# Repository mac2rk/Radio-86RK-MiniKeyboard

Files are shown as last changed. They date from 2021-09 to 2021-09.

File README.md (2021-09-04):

# Mini Keyboard for Radio-86RK

A mini keyboard for Radio-86RK, a 1986 DIY 8-bit home computer.
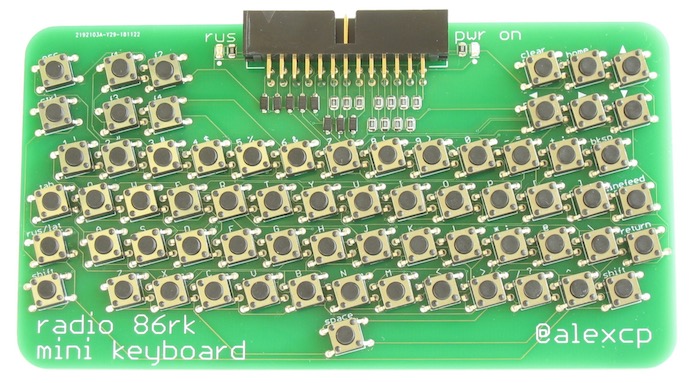
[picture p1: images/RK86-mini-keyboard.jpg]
Radio-86RK Mini Keyboard


## Introduction

When I designed my [Radio-86RK-SRAM](https://github.com/mac2rk/Radio-86RK-SRAM) remake of the 1986 DIY 8-bit home computer, I built in a PS/2 keyboard adapter to stay away from homebrew keyboards and use a commercial full-size keyboard instead. I found, however, that in many cases the full size keyboard took too much space, so I designed a mini matrix keyboard built from tact momentary switches. The design was inspired by the [Hackaday Belgrade 2018 conference badge](https://hackaday.com/2018/05/15/retro-computer-badge-for-hackaday-belgrade-has-everything-you-wished-for-back-in-the-day/).

Due to the large number of SMT tact buttons, it is easier to solder in an SMT over or with hot air. Normal manual soldering is quite possible, too.

## Schematic and PCB layout
[Schematic](Eagle/rk86-kbd-schematic.pdf)

[PCB layout](Eagle/rk86-kbd-silk.pdf)

## Bill of Materials

Device                | Package   | Quantity
--------------------- | --------- | -------
Tact momentary switch | 6x6mm SMT | 67
Resistor 2kOhm        | 0805      | 11
Resistor 330Ohm       | 0805      | 2
1N4148W diode         | SOD-123   | 8
LED                   | 0805      | 2
2x13 box header       | Right Angle | 1

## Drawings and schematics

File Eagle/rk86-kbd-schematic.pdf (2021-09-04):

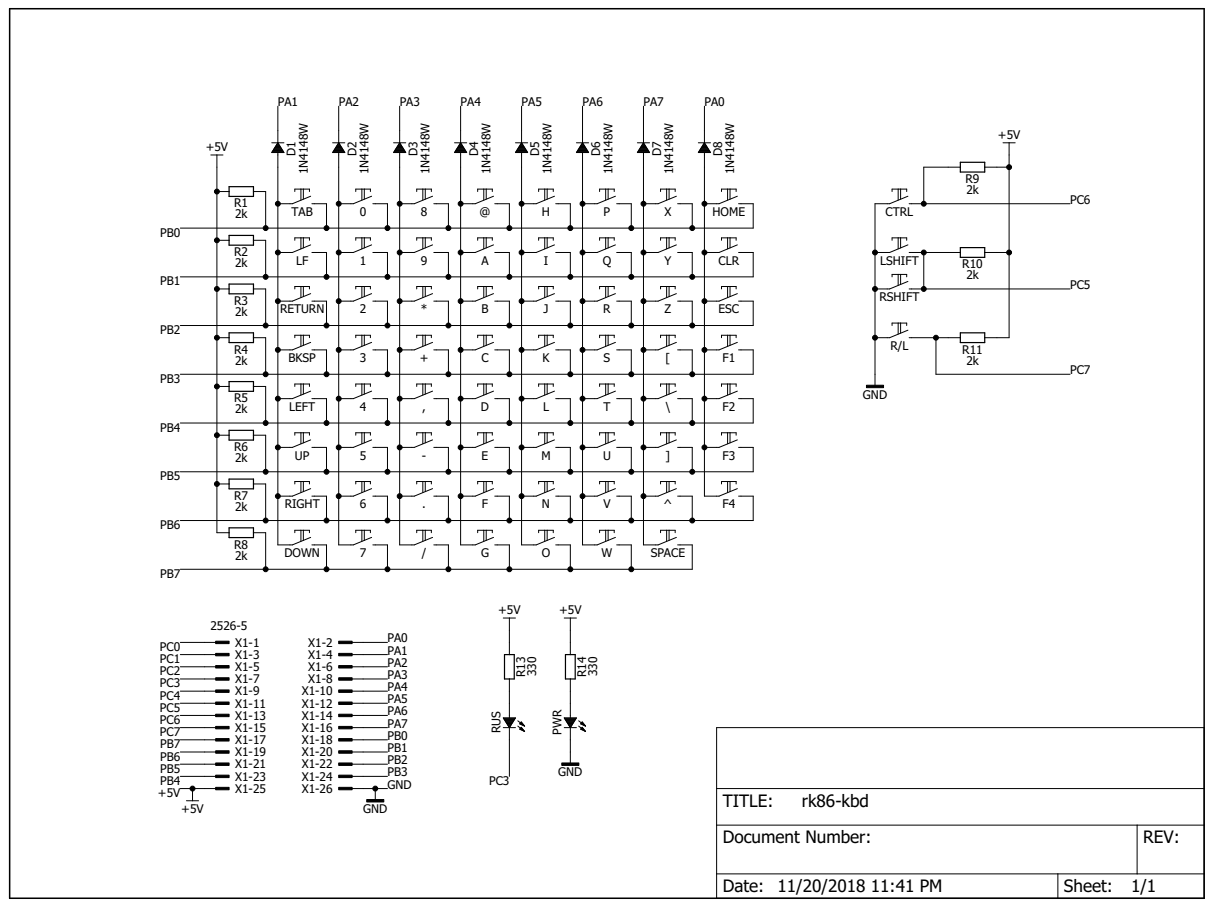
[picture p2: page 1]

Document Number: | REV:

Date: 11/20/2018 11:41 PM | Sheet: 1/1

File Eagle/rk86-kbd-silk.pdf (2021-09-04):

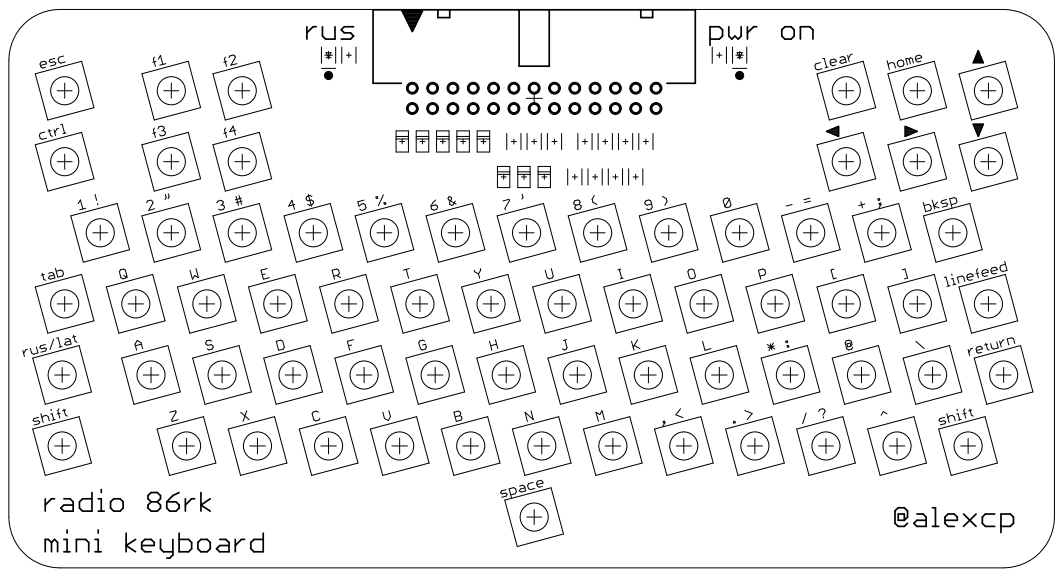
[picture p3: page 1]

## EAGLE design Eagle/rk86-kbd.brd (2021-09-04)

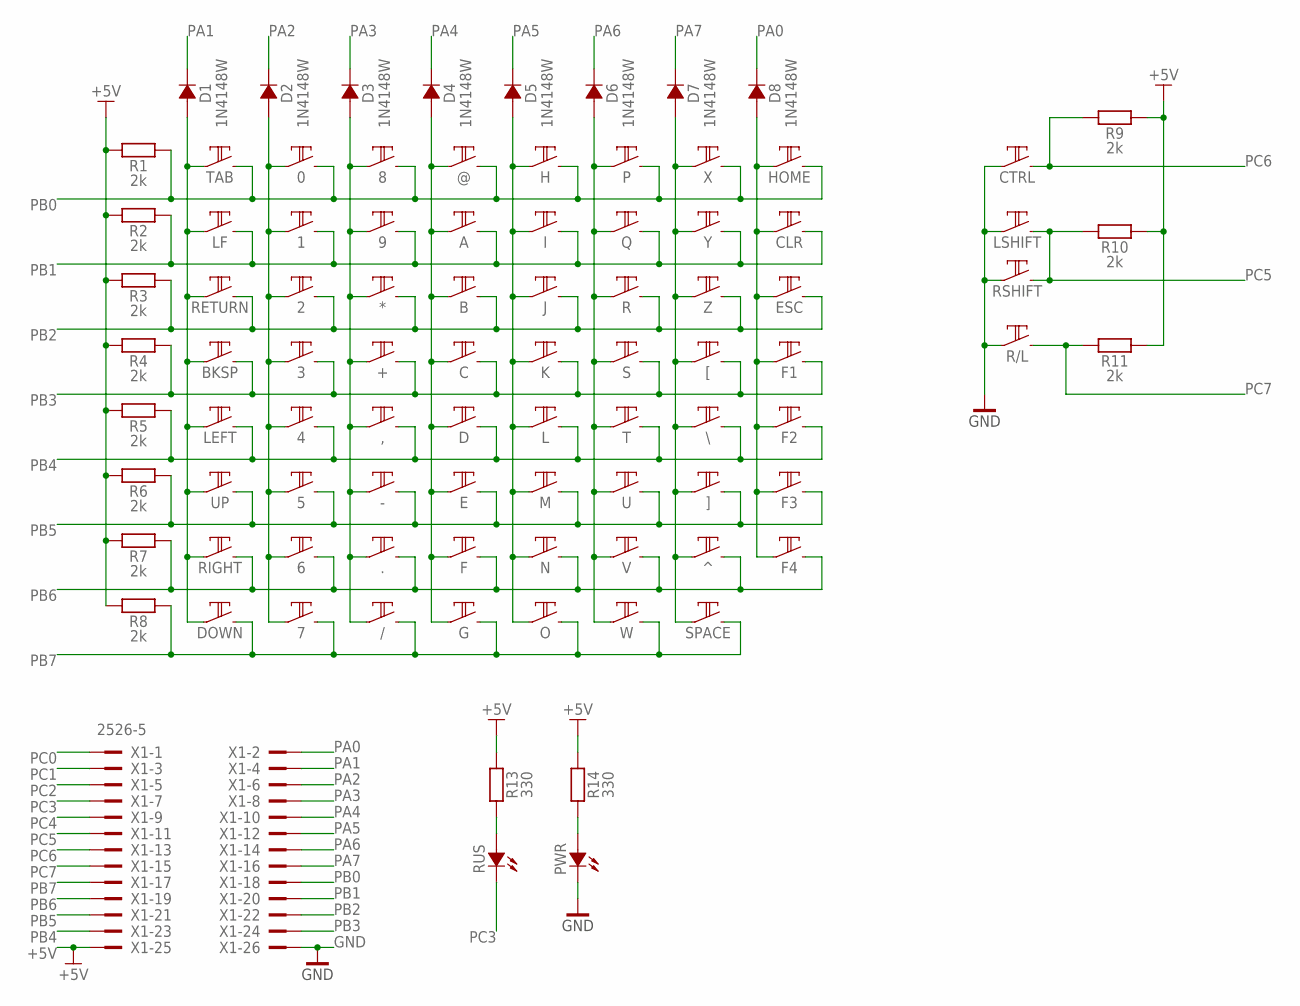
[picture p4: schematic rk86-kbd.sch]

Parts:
0, 1, 2, 3, 4, 5, 6, 7, 8, 9, .: TACT6S-15; TACT_6X6_SMT_15
*: TACT6S-15; TACT_6X6_SMT_15
+: TACT6S-15; TACT_6X6_SMT_15
,: TACT6S-15; TACT_6X6_SMT_15
-: TACT6S-15; TACT_6X6_SMT_15
/: TACT6S-15; TACT_6X6_SMT_15
@: TACT6S-15; TACT_6X6_SMT_15
A: TACT6S-15; TACT_6X6_SMT_15
B: TACT6S-15; TACT_6X6_SMT_15
BKSP: TACT6S-15; TACT_6X6_SMT_15
C: TACT6S-15; TACT_6X6_SMT_15
CLR: TACT6S-15; TACT_6X6_SMT_15
CTRL: TACT6S-15; TACT_6X6_SMT_15
D: TACT6S-15; TACT_6X6_SMT_15
D1, D2, D3, D4, D5, D6, D7, D8: 1N4148W; SOD123
DOWN: TACT6S-15; TACT_6X6_SMT_15
E: TACT6S-15; TACT_6X6_SMT_15
ESC: TACT6S-15; TACT_6X6_SMT_15
F, F1, F2, F3, F4: TACT6S-15; TACT_6X6_SMT_15
G: TACT6S-15; TACT_6X6_SMT_15
H: TACT6S-15; TACT_6X6_SMT_15
HOME: TACT6S-15; TACT_6X6_SMT_15
I: TACT6S-15; TACT_6X6_SMT_15
J: TACT6S-15; TACT_6X6_SMT_15
K: TACT6S-15; TACT_6X6_SMT_15
L: TACT6S-15; TACT_6X6_SMT_15
LEFT: TACT6S-15; TACT_6X6_SMT_15
LF: TACT6S-15; TACT_6X6_SMT_15
LSHIFT: TACT6S-15; TACT_6X6_SMT_15
M: TACT6S-15; TACT_6X6_SMT_15
N: TACT6S-15; TACT_6X6_SMT_15
O: TACT6S-15; TACT_6X6_SMT_15
P: TACT6S-15; TACT_6X6_SMT_15
PWR: LED0805; 0805POL
Q: TACT6S-15; TACT_6X6_SMT_15
R: TACT6S-15; TACT_6X6_SMT_15
R1, R2, R3, R4, R5, R6, R7, R8, R9, R10, R11: 2k; 0805
R13, R14: 330; 0805
R/L: TACT6S-15; TACT_6X6_SMT_15
RETURN: TACT6S-15; TACT_6X6_SMT_15
RIGHT: TACT6S-15; TACT_6X6_SMT_15
RSHIFT: TACT6S-15; TACT_6X6_SMT_15
RUS: LED0805; 0805POL
S: TACT6S-15; TACT_6X6_SMT_15
SPACE: TACT6S-15; TACT_6X6_SMT_15
T: TACT6S-15; TACT_6X6_SMT_15
TAB: TACT6S-15; TACT_6X6_SMT_15
U: TACT6S-15; TACT_6X6_SMT_15
UP: TACT6S-15; TACT_6X6_SMT_15
V: TACT6S-15; TACT_6X6_SMT_15
W: TACT6S-15; TACT_6X6_SMT_15
X: TACT6S-15; TACT_6X6_SMT_15
X1: 2526-5; PAK100/2500-5-26
Y: TACT6S-15; TACT_6X6_SMT_15
Z: TACT6S-15; TACT_6X6_SMT_15
[: TACT6S-15; TACT_6X6_SMT_15
\\: TACT6S-15; TACT_6X6_SMT_15
]: TACT6S-15; TACT_6X6_SMT_15
^: TACT6S-15; TACT_6X6_SMT_15

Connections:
+5V: R1.1, R2.1, R3.1, R4.1, R5.1, R6.1, R7.1, R8.1, R9.2, R10.2, R11.2, R13.2, R14.2, X1.25
GND: CTRL.1 (C), CTRL.2 (C), LSHIFT.1 (C), LSHIFT.2 (C), PWR.K, R/L.1 (C), R/L.2 (C), RSHIFT.1 (C), RSHIFT.2 (C), X1.26
unnamed: R13.1, RUS.A
unnamed: PWR.A, R14.1
PA0: D8.K, X1.2
PA0D: CLR.1 (C), CLR.2 (C), D8.A, ESC.1 (C), ESC.2 (C), F1.1 (C), F1.2 (C), F2.1 (C), F2.2 (C), F3.1 (C), F3.2 (C), F4.1 (C), F4.2 (C), HOME.1 (C), HOME.2 (C)
PA1: D1.K, X1.4
PA1D: BKSP.1 (C), BKSP.2 (C), D1.A, DOWN.1 (C), DOWN.2 (C), LEFT.1 (C), LEFT.2 (C), LF.1 (C), LF.2 (C), RETURN.1 (C), RETURN.2 (C), RIGHT.1 (C), RIGHT.2 (C), TAB.1 (C), TAB.2 (C), UP.1 (C), UP.2 (C)
PA2: D2.K, X1.6
PA2D: 0.1 (C), 0.2 (C), 1.1 (C), 1.2 (C), 2.1 (C), 2.2 (C), 3.1 (C), 3.2 (C), 4.1 (C), 4.2 (C), 5.1 (C), 5.2 (C), 6.1 (C), 6.2 (C), 7.1 (C), 7.2 (C), D2.A
PA3: D3.K, X1.8
PA3D: 8.1 (C), 8.2 (C), 9.1 (C), 9.2 (C), *.1 (C), *.2 (C), +.1 (C), +.2 (C), ,.1 (C), ,.2 (C), -.1 (C), -.2 (C), ..1 (C), ..2 (C), /.1 (C), /.2 (C), D3.A
PA4: D4.K, X1.10
PA4D: @.1 (C), @.2 (C), A.1 (C), A.2 (C), B.1 (C), B.2 (C), C.1 (C), C.2 (C), D.1 (C), D.2 (C), D4.A, E.1 (C), E.2 (C), F.1 (C), F.2 (C), G.1 (C), G.2 (C)
PA5: D5.K, X1.12
PA5D: D5.A, H.1 (C), H.2 (C), I.1 (C), I.2 (C), J.1 (C), J.2 (C), K.1 (C), K.2 (C), L.1 (C), L.2 (C), M.1 (C), M.2 (C), N.1 (C), N.2 (C), O.1 (C), O.2 (C)
PA6: D6.K, X1.14
PA6D: D6.A, P.1 (C), P.2 (C), Q.1 (C), Q.2 (C), R.1 (C), R.2 (C), S.1 (C), S.2 (C), T.1 (C), T.2 (C), U.1 (C), U.2 (C), V.1 (C), V.2 (C), W.1 (C), W.2 (C)
PA7: D7.K, X1.16
PA7D: D7.A, SPACE.1 (C), SPACE.2 (C), X.1 (C), X.2 (C), Y.1 (C), Y.2 (C), Z.1 (C), Z.2 (C), [.1 (C), [.2 (C), \\.1 (C), \\.2 (C), ].1 (C), ].2 (C), ^.1 (C), ^.2 (C)
PB0: 0.3 (NO), 0.4 (NO), 8.3 (NO), 8.4 (NO), @.3 (NO), @.4 (NO), H.3 (NO), H.4 (NO), HOME.3 (NO), HOME.4 (NO), P.3 (NO), P.4 (NO), R1.2, TAB.3 (NO), TAB.4 (NO), X.3 (NO), X.4 (NO), X1.18
PB1: 1.3 (NO), 1.4 (NO), 9.3 (NO), 9.4 (NO), A.3 (NO), A.4 (NO), CLR.3 (NO), CLR.4 (NO), I.3 (NO), I.4 (NO), LF.3 (NO), LF.4 (NO), Q.3 (NO), Q.4 (NO), R2.2, X1.20, Y.3 (NO), Y.4 (NO)
PB2: 2.3 (NO), 2.4 (NO), *.3 (NO), *.4 (NO), B.3 (NO), B.4 (NO), ESC.3 (NO), ESC.4 (NO), J.3 (NO), J.4 (NO), R.3 (NO), R.4 (NO), R3.2, RETURN.3 (NO), RETURN.4 (NO), X1.22, Z.3 (NO), Z.4 (NO)
PB3: 3.3 (NO), 3.4 (NO), +.3 (NO), +.4 (NO), BKSP.3 (NO), BKSP.4 (NO), C.3 (NO), C.4 (NO), F1.3 (NO), F1.4 (NO), K.3 (NO), K.4 (NO), R4.2, S.3 (NO), S.4 (NO), X1.24, [.3 (NO), [.4 (NO)
PB4: 4.3 (NO), 4.4 (NO), ,.3 (NO), ,.4 (NO), D.3 (NO), D.4 (NO), F2.3 (NO), F2.4 (NO), L.3 (NO), L.4 (NO), LEFT.3 (NO), LEFT.4 (NO), R5.2, T.3 (NO), T.4 (NO), X1.23, \\.3 (NO), \\.4 (NO)
PB5: 5.3 (NO), 5.4 (NO), -.3 (NO), -.4 (NO), E.3 (NO), E.4 (NO), F3.3 (NO), F3.4 (NO), M.3 (NO), M.4 (NO), R6.2, U.3 (NO), U.4 (NO), UP.3 (NO), UP.4 (NO), X1.21, ].3 (NO), ].4 (NO)
PB6: 6.3 (NO), 6.4 (NO), ..3 (NO), ..4 (NO), F.3 (NO), F.4 (NO), F4.3 (NO), F4.4 (NO), N.3 (NO), N.4 (NO), R7.2, RIGHT.3 (NO), RIGHT.4 (NO), V.3 (NO), V.4 (NO), X1.19, ^.3 (NO), ^.4 (NO)
PB7: 7.3 (NO), 7.4 (NO), /.3 (NO), /.4 (NO), DOWN.3 (NO), DOWN.4 (NO), G.3 (NO), G.4 (NO), O.3 (NO), O.4 (NO), R8.2, SPACE.3 (NO), SPACE.4 (NO), W.3 (NO), W.4 (NO), X1.17
PC0: X1.1
PC1: X1.3
PC2: X1.5
PC3: RUS.K, X1.7
PC4: X1.9
PC5: LSHIFT.3 (NO), LSHIFT.4 (NO), R10.1, RSHIFT.3 (NO), RSHIFT.4 (NO), X1.11
PC6: CTRL.3 (NO), CTRL.4 (NO), R9.1, X1.13
PC7: R11.1, R/L.3 (NO), R/L.4 (NO), X1.15

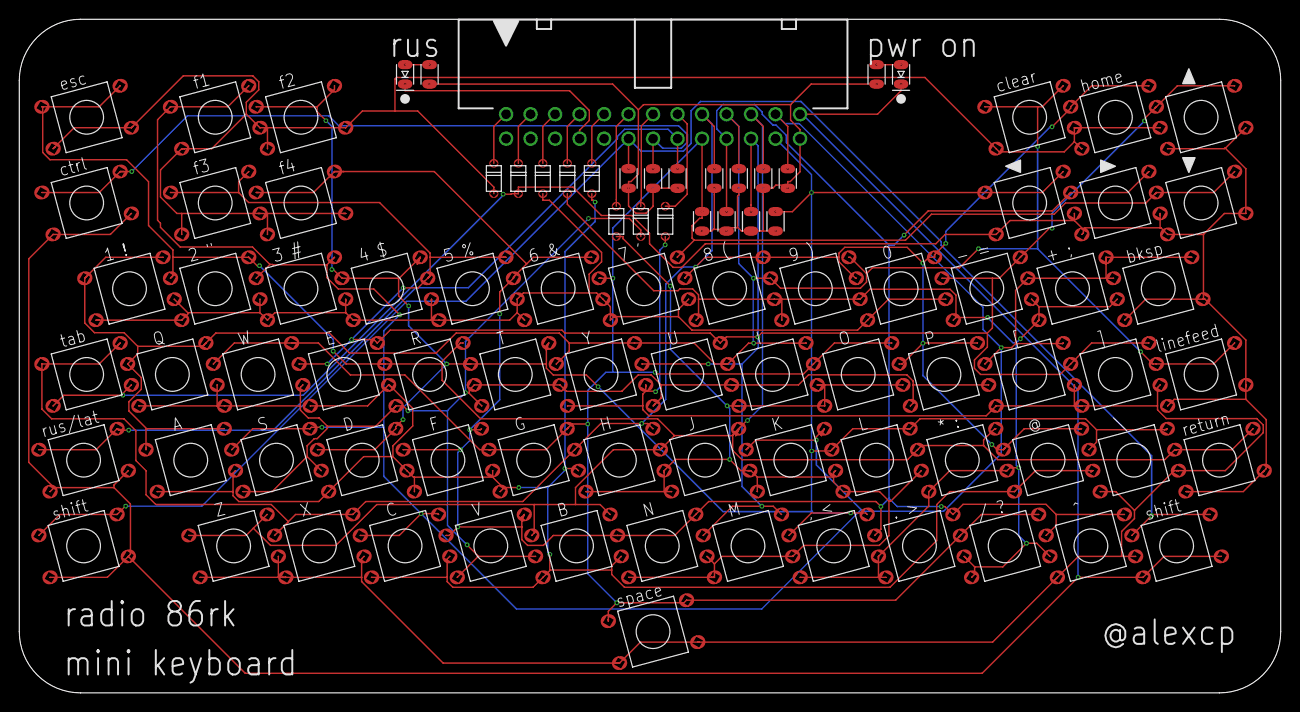
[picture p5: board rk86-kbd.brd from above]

Board: 2 copper layers, 130.8 x 69.8 mm, 91 parts (0 on the bottom side), 32 nets.
